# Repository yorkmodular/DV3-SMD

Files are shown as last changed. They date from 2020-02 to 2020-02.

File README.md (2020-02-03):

## York Modular DV3 - Dual AR Envelope Generator/Slew Limiter

This is the third iteration of my 'Drumvelope' AR module - the main improvement being that it now comes with twice as many envelope generators. That is, two instead of one ...

If you want a nice, simple envelope generator aimed at use in percussion patches then this is it. Better still, you can also use it as a slew limiter if you're so inclined - bear in mind, however, that the response is exponential, rather than linear.

### Construction notes
Other than being SMD, there are no particular gotchas associated with this build. 

The attack/release rates are controlled by capacitors C1 and C8 - for pre-built units I generally use 2.2μF caps, but this value isn't set in stone by any means. Higher values will lead to longer attack/release times, and vice versa, although using capacitors less than 1μF isn't recommended as you may end up with values that are too small to be useful - ultimately this is a judgement call.

Log-taper pots are recommended - you'll have far more control over the attack/release values this way. 1M should give you a good range of values. Alpha pots are recommended since they'll afford a bit more support to the panel than just using the jacks alone.

### Files

* `dv3-schematic.png` - the schematic.
* `dv3-BOM.xlsx` - the BOM (Bill of Materials) file
* `dv3-panel.dxf` - the panel file in AutoCAD DXF format.
* `dv3-panel.fpd` - the panel file in Schaeffer FPD format. If you want to customise the panel then use this file and re-export it as a DXF or SVG file.

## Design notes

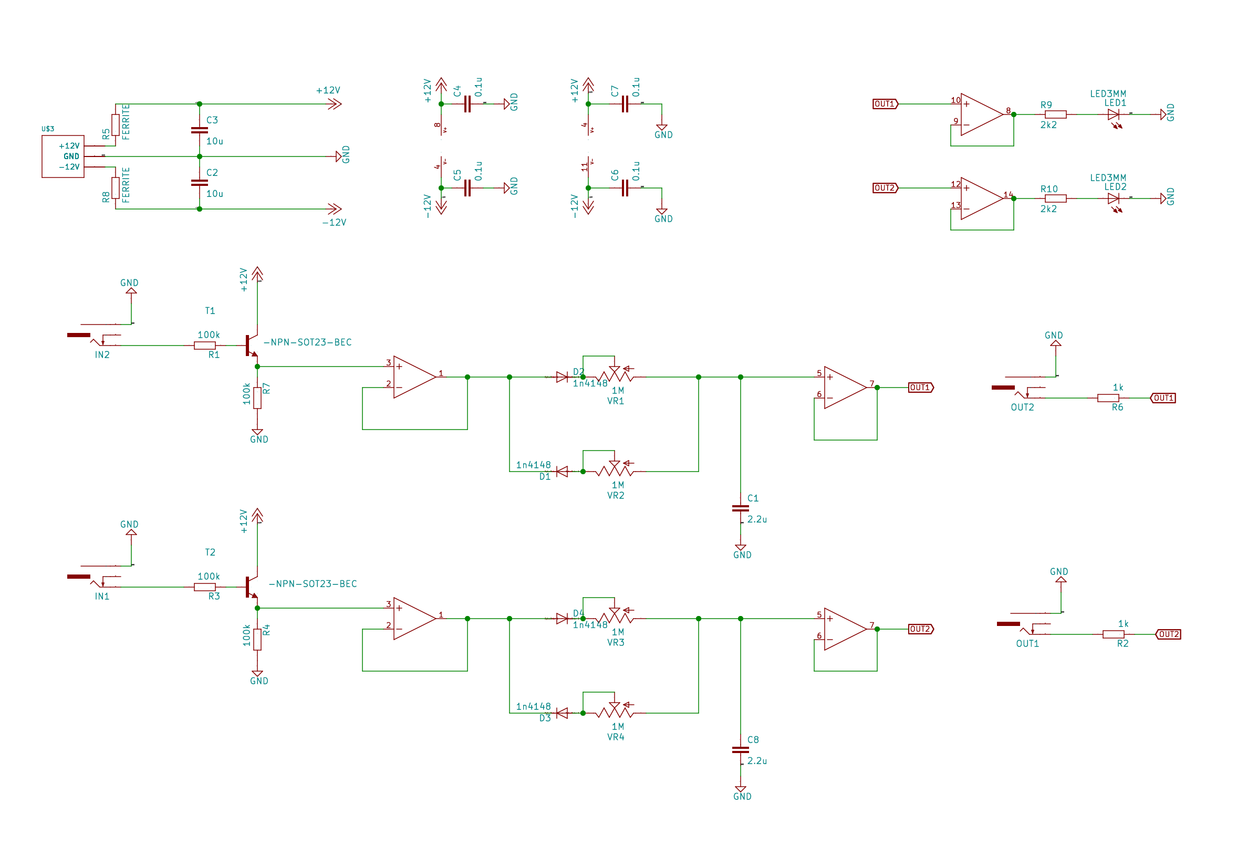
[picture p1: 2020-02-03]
dv3-schematic.png

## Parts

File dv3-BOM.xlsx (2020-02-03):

Designator | Package | Quantity | Designation | Notes
C1,C8 | C0805 | 2 | 2.2u | This is my stock value – gives a time constant of 2sec or thereabouts. Higher capacitance => longer attack/decay. Values less than 1u aren’t recommended[*]
C2,C3 | C0805 | 2 | 10u
C4,C5,C6,C7 | C0805 | 4 | 0.1u
D1,D2,D3,D4 | SOD323-W | 4 | 1n4148 | Any small-signal diode should work – 1N4148WS are the go-to choice.
R1,R3,R4,R7 | R0805 | 4 | 100k
R2,R6 | R0805 | 2 | 1k
R5,R8 | R0805 | 2 | FERRITE | Can also use a 22R resistor if ferrites aren’t available
R9,R10 | R0805 | 2 | 2k2 | LED current limiting resistor – can use 470R or 1k if you’re not using high brightness LEDs.
VR1,VR2,VR3,VR4 | 9MM_SNAP-IN_POT | 4 | 1M | Log taper – Alpha T-18 recommended, although anything with a compatible footprint will work.
U$3 | POWER_10 | 1 | POWER_SIMPLE10 | 2x5 DIL headers, 2.54mm centres. The chevron on the silkscreen indicates -12V
IC1 | SO14 | 1 | TL074D | Any pin-compatible quad op-amp will work
OUT2,IN2,OUT1,IN1 | WQP-PJ301M-12_JACK | 4 | THONKICONNNEW | ThonkIcon 3.5mm jack.
T1,T2 | SOT23-BEC | 2 | MMBT3904 | Pretty much any small-signal NPN transistor will work.
IC3 | SO08 | 1 | TL072D | Any pin compatible dual op-amp will work
LED1,LED2 | LED3MM | 2 | LED3MM | Any colour you like … the LEDs are buffered.
 |  |  |  | [*] - not to say that you can’t use a cap smaller than 1u, however it may leave you with attack/decay times that are too short to be useful.

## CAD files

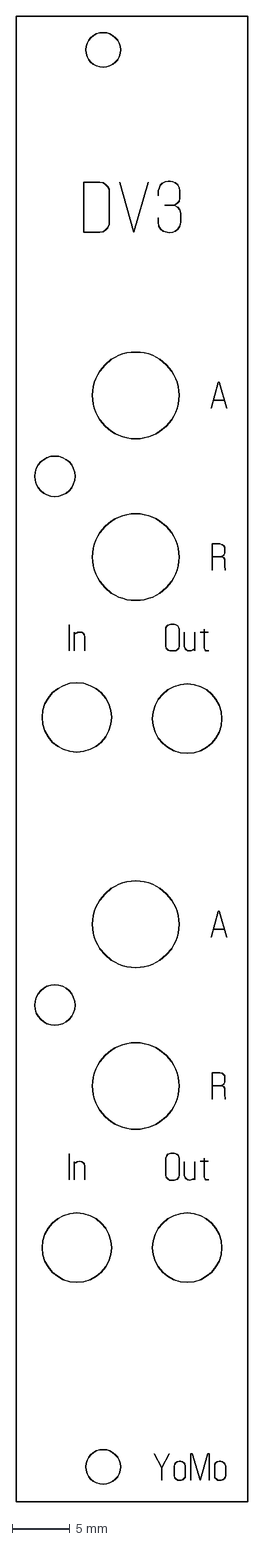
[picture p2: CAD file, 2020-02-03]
dv3-panel.dxf
20.0 x 128.4 mm
